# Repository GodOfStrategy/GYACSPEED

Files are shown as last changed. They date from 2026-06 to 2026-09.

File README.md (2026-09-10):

# GYACSPEED
Speedometer, accelerometer and a gyroscope for my bicycle, with the XIAO RP2040 as the MCU, with a 2.4" TFT (no touchscreen) display (connected with jumpers) for the information.
I saw the Hermes starter project and though, "Why only stop at a gyroscope?" and then answered my own question by adding a speedometer powered by the Ublox NEO-M9N GNSS module, and a gyroscope and an accelerometer powered by the LSM6DSLTR!! So that I can see my speed, acceleration, and how I take turn using the gyroscope and such, with the XIAO RP2040 serving as my MCU. I made this project because, well, I thought that Hermes was cool but then realized that only a gyroscope isn't that useful after all. I thought about an all-in-one bicycle dashboard, complete with a speedometer, odometer (calculated from the GPS module), accelerometer (to see the derivative of velocity ;) ). My bicycle isn't really a smart bicycle so it doesn't have all these features built-in like some other smart bicycles.
So, I drew the Schematics:

Then I routed the PCB

How my assembled PCB is supposed to look like:{270DA254-DB51-4898-A8E7-48D921C7D5DD}

Then I designed a case in Fusion 360 for my project, and found solutions so as to how will I mount it on my bicycle and then came up with this monstrosity:




The idea of the mount is to be modular and help me join the two parts by using a single mount. The mount is based on the idea of mounting the project on my bicycle handle bar. I took some measurements and made a cylinder with walls which would wrap around my bicycle bar. After that I added an extension to the cylinder with a flat base, where I added the screw holes. I then added a triangular kind of part to join the cylinder with my main project case.

Instructions on Assembling:
1. Solder the Header Pins.
2. seat the pcb into the top case.
3. Now there is an opening in the bottom of the top case to allow jumpers from the Li-Po to connect with the Main PCB as shown here: 
4. The hole on the side of the bottom [battery] case looks like so: 
5. Run two jumpers connecting the Battery to the PCB, the left pin on the main PCB is the +ve terminal, as mentioned on the silkscreen.
6. There are mounting holes on tft module that I will be purchasing, and I have also added holes on my case top so that I can secure the display. To do so, we place the Display on the bottom of the top case like so:  and then insert bolts(M3/ 15mm) form the top : and screw them with the nuts tightly.
7. Then we again use jumper wires to connect the display to the pcb 
after which we place the top case cover on the top case and put 30 mm M3 bolts through the screw holes and secure them with M3 nuts.
8. For the bottom case, we insert our battery in the main bottom case, run the jumpers to the main PCB through the openings, and then We put the case cover on, and screw it using M3 30mm bolts and M3 nuts.
9. Now, we have two modules, to mount them together on a bicycle handlebar, we simply put them on the bicycle bar and then screw the both together in this mount-ish-part 
using the screw holes, and M3 15mm bolts along with M3 nuts.
Thats it! You're done

Here is my BoM (which you can find in the root of my repository as well):

|Designator|Footprint|Quantity|Value|LCSC Part #|Price (US $)|Links|Distributor|Generic Name|
|---|---|---|---|---|---|---|---|---|
| C1 | 805 | 5.0 | 100uF |  | 3.54 | GRM21BR60E107ME15K Murata Electronics \| Mouser India | Mouser India | Capacitors |
| C10, C3, C4, C5 | 402 | 10.0 | 10uF |  | 0.46 | https://www.mouser.in/ProductDetail/TAIYO-YUDEN/MSASJ105CB5106MFNC12?qs=PBDs2xEllI8xKzMj03Wyvw%3D%3D | Mouser India |  |
| C11, C12, C7, C8, C9 | 402 | 5.0 | 0.1uF |  | 0.24 | https://www.mouser.in/ProductDetail/80-C0402C104K4P | Mouser India |  |
| C2 | 402 | 1.0 | 1pF |  | 0.25 | 04023A1R0DAT2A KYOCERA AVX \| Mouser India |  |  |
| C6 | 402 | 10.0 | 1uF |  | 0.17 | https://www.mouser.in/ProductDetail/KYOCERA-AVX/0402X5R105KTAAT?qs=XAiT9M5g4x9uZyL2wCxs9w%3D%3D | Mouser India |  |
| D1 | D_SMA | 3.0 | SS14 |  | 1.3 | https://www.mouser.in/ProductDetail/onsemi/SS14?qs=mVVXn4M53U%252BvrBaFv5vr4w%3D%3D | Mouser India | Reverse Polarity Protection diode |
| DS1 | TFT LCD 240x320 2.4" | 2.0 | TFT LCD 2.4" SPI |  | 16.53 | [https://www.amazon.in/Tishvi-Interface-Contrast-Microcontroller-Projects/dp/B0GZQBH8TX/ref=sr_1_5?](https://www.amazon.in/SmartElex-2-4-inch-Interface-Resolution-Embedded/dp/B0GFD2GKS3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)crid=5ELFGR2Y3AVB&dib=eyJ2IjoiMSJ9.Jpr0nalYGfL14nV7bbjmTZKJv2EIKupA4PS6ncRHPeflKUuEP1chaxLUuG31tnS91O83QhHNpJtINdHxloWLYH9lf4NJ4qSOWR6nymU5ejpQAXrm3idjtpBYQ0aIwBILTmNX_3lALKvsE76wo-qvywPqliJmu2u1Sw0mh8OCet7xKizlRF5dPz3CHCYLgBtFUnNA9Eu-mYQBGu7QWCQPqbfzEN95b4kUAEvBXaaM7DjF16ZafKrP9sBf0yOEFYHzo9n5p0J-zkTF9JNQ7vyMX4nY2xR5RTSpoe2_mFh8lyM.-pu-_CBvqfhh_vnW6SlNHAERV8AtyvnIy9OJlCs-LRc&dib_tag=se&keywords=1.3%22+OLED+IIC&qid=1782751854&sprefix=1.3+oled+iic%2Caps%2C282&sr=8-5 | Amazon India | OLED |
| E1 | XCVR_ANT-GNCP-TH25AL12 | 2.0 | ANT-GNCP-TH25AL12 |  | 22.2 | https://www.mouser.in/ProductDetail/TE-Connectivity/ANT-GNCP-TH25AL12?qs=A6eO%252BMLsxmRfsTs3t3ApUw%3D%3D | Mouser India | Passive antenna |
| J1, J2 | PinHeader_1x05_P2.54mm_Vertical | 0.0 | Conn_01x05_Pin |  | 0.0 |  | Self-Sourced |  |
| J3 | PinHeader_1x02_P2.54mm_Vertical |  | Conn_01x02_Socket |  |  |  |  |  |
| L1 | 603 | 1.0 | 1 uH |  | 0.52 | https://www.mouser.in/ProductDetail/ABRACON/AIML-0603-1R0K-T?qs=1vO2EIVe%252BY7DV5QHOd2BCw%3D%3D | Mouser India | Inductor |
| Q1, Q2 | SOT-23-3_L3.0-W1.7-P0.95-LS2.9-BR | 4.0 | SI2301CDS-T1-GE3 | C10487 | 3.47 | SI2301CDS-T1-BE3 Vishay / Siliconix \| Mouser India | Mouser India | MOSFETs |
| R1 | 402 | 1.0 | 453K |  | 0.088 | RC0402FR-07453KL YAGEO \| Mouser India | Mouser India | Resistors |
| R2 | 402 | 1.0 | 100K |  | 0.37 | https://www.mouser.in/ProductDetail/YAGEO/AC0805JR-7W100KL?qs=r5DSvlrkXmI4dHdBm%2FLHKQ%3D%3D | Mouser India |  |
| R3 | 402 | 1.0 | 2.2K |  | 0.078 | RC0402JR-7D2K2L YAGEO \| Mouser India | Mouser India |  |
| R4 | 402 | 1.0 | 330 |  | 0.078 | CR0402-JW-331GLF Bourns \| Mouser India | Mouser India |  |
| U1 | XIAO-RP2040-DIP | 2.0 | XIAO-RP2040-DIP |  | 10.57 | https://www.mouser.in/ProductDetail/Seeed-Studio/102010428?qs=Znm5pLBrcAJ75FCbdxzDHQ%3D%3D | Mouser India | MCU |
| U2 | XCVR_NEO-M9N-00B | 2.0 | NEO-M9N-00B |  | 23.69 | https://www.mouser.in/ProductDetail/u-blox/NEO-M9N-00B?qs=DPoM0jnrROVeJ6BHpcwcjw%3D%3D | Mouser India | GNSS Module |
| U3 | LGA-14_3x2.5mm_P0.5mm_LayoutBorder3x4y | 2.0 | LSM6DS3 |  | 13.42 | https://www.mouser.in/ProductDetail/STMicroelectronics/LSM6DSV32XTR?qs=HoCaDK9Nz5d%252BGVBpjxkjlg%3D%3D | Mouser India | 3D Gyroscope + Accelerometer |
| U4 | VQFN-7_L2.0-W2.0-P0.55-TL_RWU | 2.0 | TPS61022RWUR | C915088 | 6.31 | TPS61022RWUR Texas Instruments \| Mouser India | Mouser India | Swirching Buck Regulator |
| U5 | WSON-6_L1.5-W1.5-P0.50-TL | 2.0 | BQ29703DSER | C2876295 | 1.12 | BQ29703DSER Texas Instruments \| Mouser India | Mouser India | Battery overdischarge protection |
|  |  | 1.0 | (cheaper and better than any hotplate on amazon[reviews for the hotplate were horrible]) |  | 37.02 | https://www.amazon.in/Soldering-600W-Adjustable-Temperature-Electronics/dp/B0DT693N47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 | Amazon India | Hot air gun [ 2 in 1] |
|  |  | 1.0 |  |  | 6.34 | https://www.amazon.in/SR-Syringe-Circuit-Assembly-Mechanic-Soldering/dp/B0H511T6TD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 | Amazon India | Soldering Paste |
|  |  | 1.0 |  |  | 4.75 | https://www.amazon.in/Desoldering-Microprocessor-Smartphones-Motherboards-Electronic/dp/B0C7N66JFQ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 | Amazon India | Flux Paste |
|  |  | 10.0 |  |  | 2.91 | https://www.amazon.in/Rpi-shop-Phillips-Countersunk-Quantity/dp/B08HNBTZ3D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 | Amazon India | M3 bolts 15mm |
|  |  | 30.0 |  |  | 3.7 | https://www.amazon.in/Invento-pcs-Head-Screws-Projects/dp/B073Z9LXB2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 | Amazon India | M3 bolts 30mm |
|  |  | 50.0 |  |  | 1.51 | https://www.amazon.in/TRO-M3-3mm-HEX-NUT-SS304-PACK/dp/B0DSWCH2XN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 | Amazon India | M3 nuts |
|  |  | 10.0 |  |  | 0.93 | https://www.amazon.in/Female-2-5mm-Cable-Connector-Silicone/dp/B0837W4DC8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 | Amazon India | 2 pin 2.5mm Cable Micro Male and Female Connector Plug For Lithium Ion Battery connector |
|  |  | 1.0 |  |  | 6.31 | https://www.amazon.in/ELBOTICS-Rechargeable-Lithium-ion-Electronics-Helicopter/dp/B0F4KQPNNH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 | Amazon India | 2 cell LiPo [2000 maH] |
|  |  | 1.0 |  |  | 1.66 | https://www.amazon.in/Step-Up-Overvoltage-Protection-Efficiency-Electronics/dp/B0FDRCPRM8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 | Amazon India | 2 cell LiPo Charger |
|  |  | 1.0 |  |  | 21.58 |Shipping|  | SHIPPING (Mouser +JLCPCB) |
|  |  | 5.0 |  |  | 5.0 |PCBs from JLCPCB|  | PCB |
|  |  | 1.0 |  |  | 7.16 |Stencil so that I can solder them myself|  | Stencil |
|  |  |  |  |  |  |  |  |  |
|  | TOTAL --> |  | 203.89 $|  |  |  |  |  |

[bom(final).csv](https://github.com/user-attachments/files/29474485/bom.final.csv)

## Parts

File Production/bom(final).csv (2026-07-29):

Designator | Footprint | Quantity | Value | LCSC Part # | Generic Name | Price (US $) | Links | Comments | Distributor
C1 | 805 | 5 | 100uF |  | Capacitors | 2.51 | https://www.mouser.in/ProductDetail/Murata/GRM21BR60G107ME11L?qs=Ey7%2FXF42M3epBQcj%2F9hW%252BQ%3D%3D |  | Mouser India
C2, C4, C5 | 402 | 10 | 10uF |  |  | 0.46 | https://www.mouser.in/ProductDetail/TAIYO-YUDEN/MSASJ105CB5106MFNC12?qs=PBDs2xEllI8xKzMj03Wyvw%3D%3D |  | Mouser India
C3 | 402 | 5 | 22uF |  |  | 3.01 | https://www.mouser.in/ProductDetail/KYOCERA-AVX/04024W226MAT2A?qs=iLbezkQI%252BsiTzMwT1ZoG%252Bw%3D%3D |  | Mouser India
C6 | 402 | 5 | 1uF |  |  | 2.07 | https://www.mouser.in/ProductDetail/KYOCERA-AVX/0402X5R105KTAAT?qs=XAiT9M5g4x9uZyL2wCxs9w%3D%3D |  | Mouser India
C7, C8 | 402 | 5 | 0.1uF |  |  | 1.87 | https://www.mouser.in/ProductDetail/KYOCERA-AVX/0402X7R104KT2AT?qs=XAiT9M5g4x9OdY6eF8NA2w%3D%3D |  | Mouser India
D1 | D_SMA | 3 | SS14 |  | Reverse Polarity Protection Diode | 1.3 | https://www.mouser.in/ProductDetail/onsemi/SS14?qs=mVVXn4M53U%252BvrBaFv5vr4w%3D%3D |  | Mouser India
 |  | 2 |  |  | 2.4" SPI TFT LCD | 16.53 | https://www.amazon.in/SmartElex-2-4-inch-Interface-Resolution-Embedded/dp/B0GFD2GKS3 |  | Amazon India
E1 | XCVR_ANT-GNCP-TH25AL12 | 2 | ANT-GNCP-TH25AL12 |  | Ceramic Patch Antenna | 22.2 | https://www.mouser.in/ProductDetail/TE-Connectivity/ANT-GNCP-TH25AL12?qs=A6eO%252BMLsxmRfsTs3t3ApUw%3D%3D |  | Mouser India
J1, J2 | PinHeader_1x05_P2.54mm_Vertical | 2 | Conn_01x05_Pin |  | Pin headers | 0 |  |  | Self Sourced
J3 | PinHeader_1x02_P2.54mm_Vertical | 1 | Conn_01x02_Socket
L1 | 805 | 5 | 2.2uH |  | Inductor | 2.81 | https://www.mouser.in/ProductDetail/TDK/B82498F1222J?qs=iux7VCIsw53%252Bh%2F5GwBAxhg%3D%3D |  | Mouser India
PS1 | WSON-8_L2.0-W2.0-P0.50-TL-EP | 3 | TPS62163DSGR | C97534 | Switching Buck Regulator | 5.09 | https://www.mouser.in/ProductDetail/Texas-Instruments/TPS62163DSGR?qs=gXEV9p%2FxLgeWmbvztTvegw%3D%3D |  | Mouser India
R1 | 805 | 10 | 100K |  | Resistor | 0.37 | https://www.mouser.in/ProductDetail/YAGEO/AC0805JR-7W100KL?qs=r5DSvlrkXmI4dHdBm%2FLHKQ%3D%3D |  | Mouser India
R2 | 402 | 10 | 4.7K |  |  | 0.12 | https://www.mouser.in/ProductDetail/YAGEO/RC0402JR-104K7L?qs=qpJ%252B%252B%252Bdg6p1vPUiz5W4RZg%3D%3D |  | Mouser India
R3 | 402 |  |  |  |  |  |  |  | Mouser India
U1 | XIAO-RP2040-DIP | 2 | XIAO-RP2040-DIP |  | MCU | 10.57 | https://www.mouser.in/ProductDetail/Seeed-Studio/102010428?qs=Znm5pLBrcAJ75FCbdxzDHQ%3D%3D |  | Mouser India
U2 | XCVR_NEO-M9N-00B | 2 | NEO-M9N-00B |  | GNSS Module | 23.69 | https://www.mouser.in/ProductDetail/u-blox/NEO-M9N-00B?qs=DPoM0jnrROVeJ6BHpcwcjw%3D%3D |  | Mouser India
U3 | LGA-14_3x2.5mm_P0.5mm_LayoutBorder3x4y | 2 | LSM6DS3 |  | 3D Gyroscope + Accelerometer | 13.42 | https://www.mouser.in/ProductDetail/STMicroelectronics/LSM6DSV32XTR?qs=HoCaDK9Nz5d%252BGVBpjxkjlg%3D%3D |  | Mouser India
PCB |  |  |  |  |  | 4 |  |  | JLCPCB
Stencil |  |  |  |  |  | 7.16 |  |  | JLCPCB
 |  | 1 |  |  | Hot air gun [ 2 in 1] | 37.02 | https://www.amazon.in/Soldering-600W-Adjustable-Temperature-Electronics/dp/B0DT693N47 | (cheaper and better than any hotplate on amazon[reviews for the hotplate were horrible]) | Amazon India
 |  | 1 |  |  | Soldering Paste | 6.34 | https://www.amazon.in/SR-Syringe-Circuit-Assembly-Mechanic-Soldering/dp/B0H511T6TD |  | Amazon India
 |  | 1 |  |  | Flux Paste | 4.75 | https://www.amazon.in/Desoldering-Microprocessor-Smartphones-Motherboards-Electronic/dp/B0C7N66JFQ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 |  | Amazon India
 |  | 10 |  |  | M3 bolts 15mm | 2.91 | https://www.amazon.in/Rpi-shop-Phillips-Countersunk-Quantity/dp/B08HNBTZ3D |  | Amazon India
 |  | 30 |  |  | M3 bolts 30mm | 3.7 | https://www.amazon.in/Invento-pcs-Head-Screws-Projects/dp/B073Z9LXB2 |  | Amazon India
 |  | 50 |  |  | M3 nuts | 1.51 | https://www.amazon.in/TRO-M3-3mm-HEX-NUT-SS304-PACK/dp/B0DSWCH2XN |  | Amazon India
 |  | 10 |  |  | 2 pin 2.5mm Cable Micro Male and Female Connector Plug For Lithium Ion Battery connector | 0.93 | https://www.amazon.in/Female-2-5mm-Cable-Connector-Silicone/dp/B0837W4DC8?nsdOptOutParam=true |  | Amazon India
 |  | 1 |  |  | 2 cell LiPo [2000 maH] | 6.31 | https://www.amazon.in/ELBOTICS-Rechargeable-Lithium-ion-Electronics-Helicopter/dp/B0F4KQPNNH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 |  | Amazon India
 |  | 1 |  |  | 2 cell LiPo Charger | 1.66 | https://www.amazon.in/Step-Up-Overvoltage-Protection-Efficiency-Electronics/dp/B0FDRCPRM8 |  | Amazon India
SHIPPING (Mouser +JLCPCB) |  |  |  |  |  | 21.58 |  | Ordering hot air gun, solder paste etc. Because getting the tools and self assembling
 |  |  |  |  | TOTAL --> | 203.89 |  | is cheaper than JLCPCBA and helps future projects also be cheaper

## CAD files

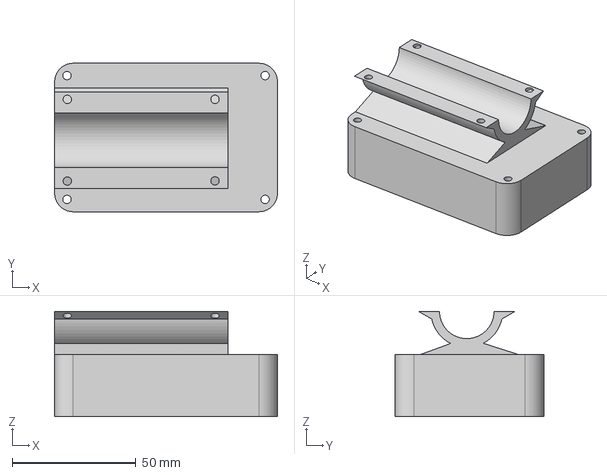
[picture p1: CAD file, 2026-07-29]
CAD/Bottom/Hermes Bottom [1].step
90.1 x 60.0 x 42.5 mm

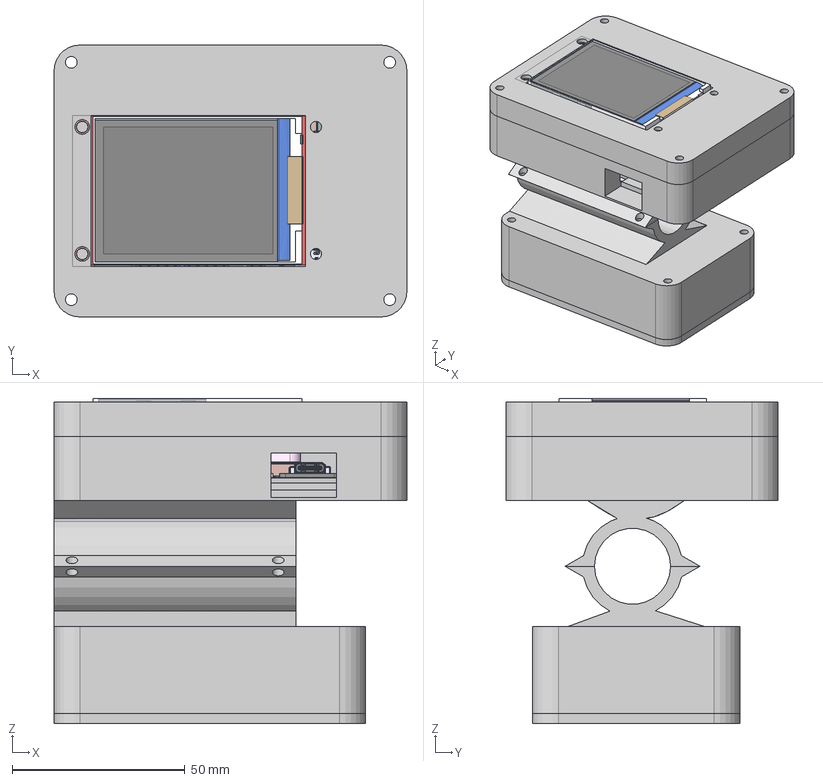
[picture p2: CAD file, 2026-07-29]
CAD/Full Assembled/Hermes [all].step
102.0 x 78.6 x 94.0 mm
SOT-23-3L_L2.9-W1.6-H1.1-LS2.8-P0.95 x 2
WSON-6_L1.5-W1.5-H0.8-P0.50-TL
R_0402_1005Metric x 4
VQFN-7_L2.0-W2.0-P0.55-TL_RWU
C_0402_1005Metric x 11
XIAO RP2040--3DModel-STEP-269445
ANT-GNCP-TH25AL12
C_0805_2012Metric
PinHeader_1x02_P2.54mm_Vertical
PinHeader_1x05_P2.54mm_Vertical x 2
PinHeader_1x04_P2.54mm_Vertical x 2
D_SMA
NEO-M9N_NEO-M9N
L_0603_1608Metric
LGA-14_3x2.5mm_P0.5mm_LayoutBorder3x4y
Hermes_silkscreen
Hermes_soldermask
Hermes_soldermask_1
Hermes_PCB
2.0 LCD TFT Module - Without Glass
0603 Resistor x 6
0603 Capacitor x 2
SOT23-3 x 2
2.4in TFT(Without Glass)- Tucked Cable

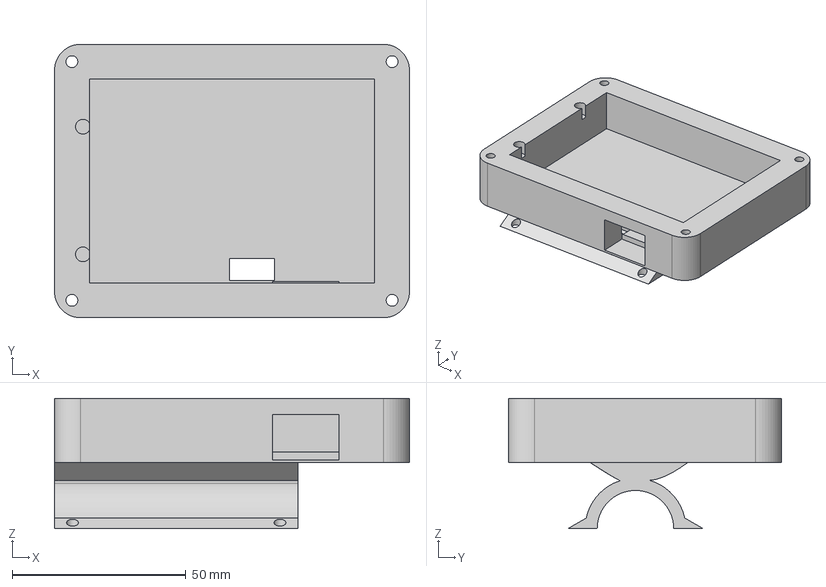
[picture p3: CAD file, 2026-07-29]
CAD/Top/Hermes top [1].step
102.0 x 78.6 x 37.5 mm

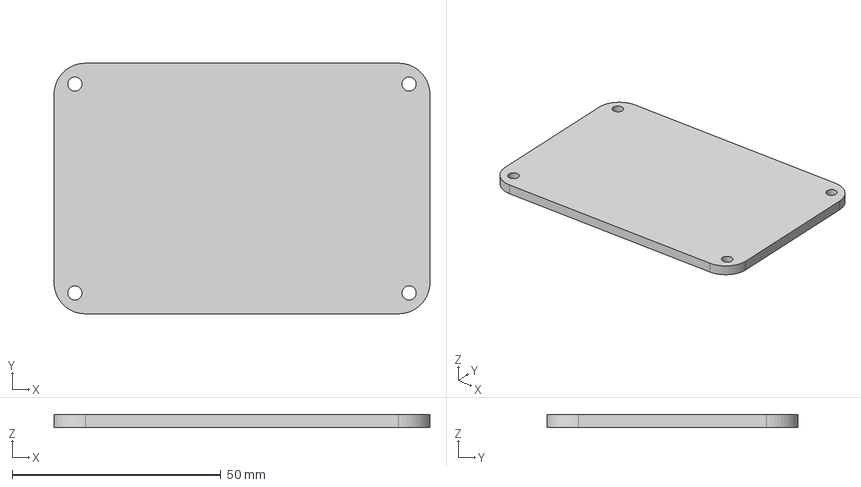
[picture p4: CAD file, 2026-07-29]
CAD/Bottom/Hermes Bottom [2].step
90.0 x 60.0 x 3.00 mm

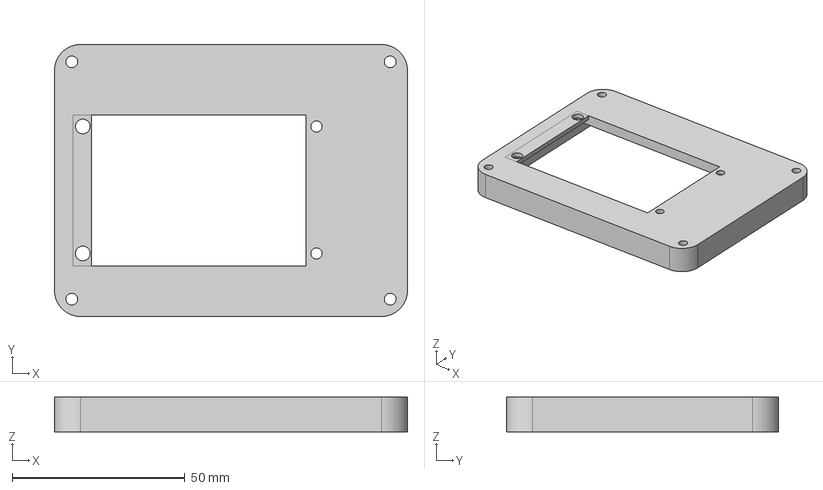
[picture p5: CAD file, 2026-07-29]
CAD/Top/Hermes top [2].step
102.0 x 78.6 x 10.0 mm

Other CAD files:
CAD/Hermesnew.f3z

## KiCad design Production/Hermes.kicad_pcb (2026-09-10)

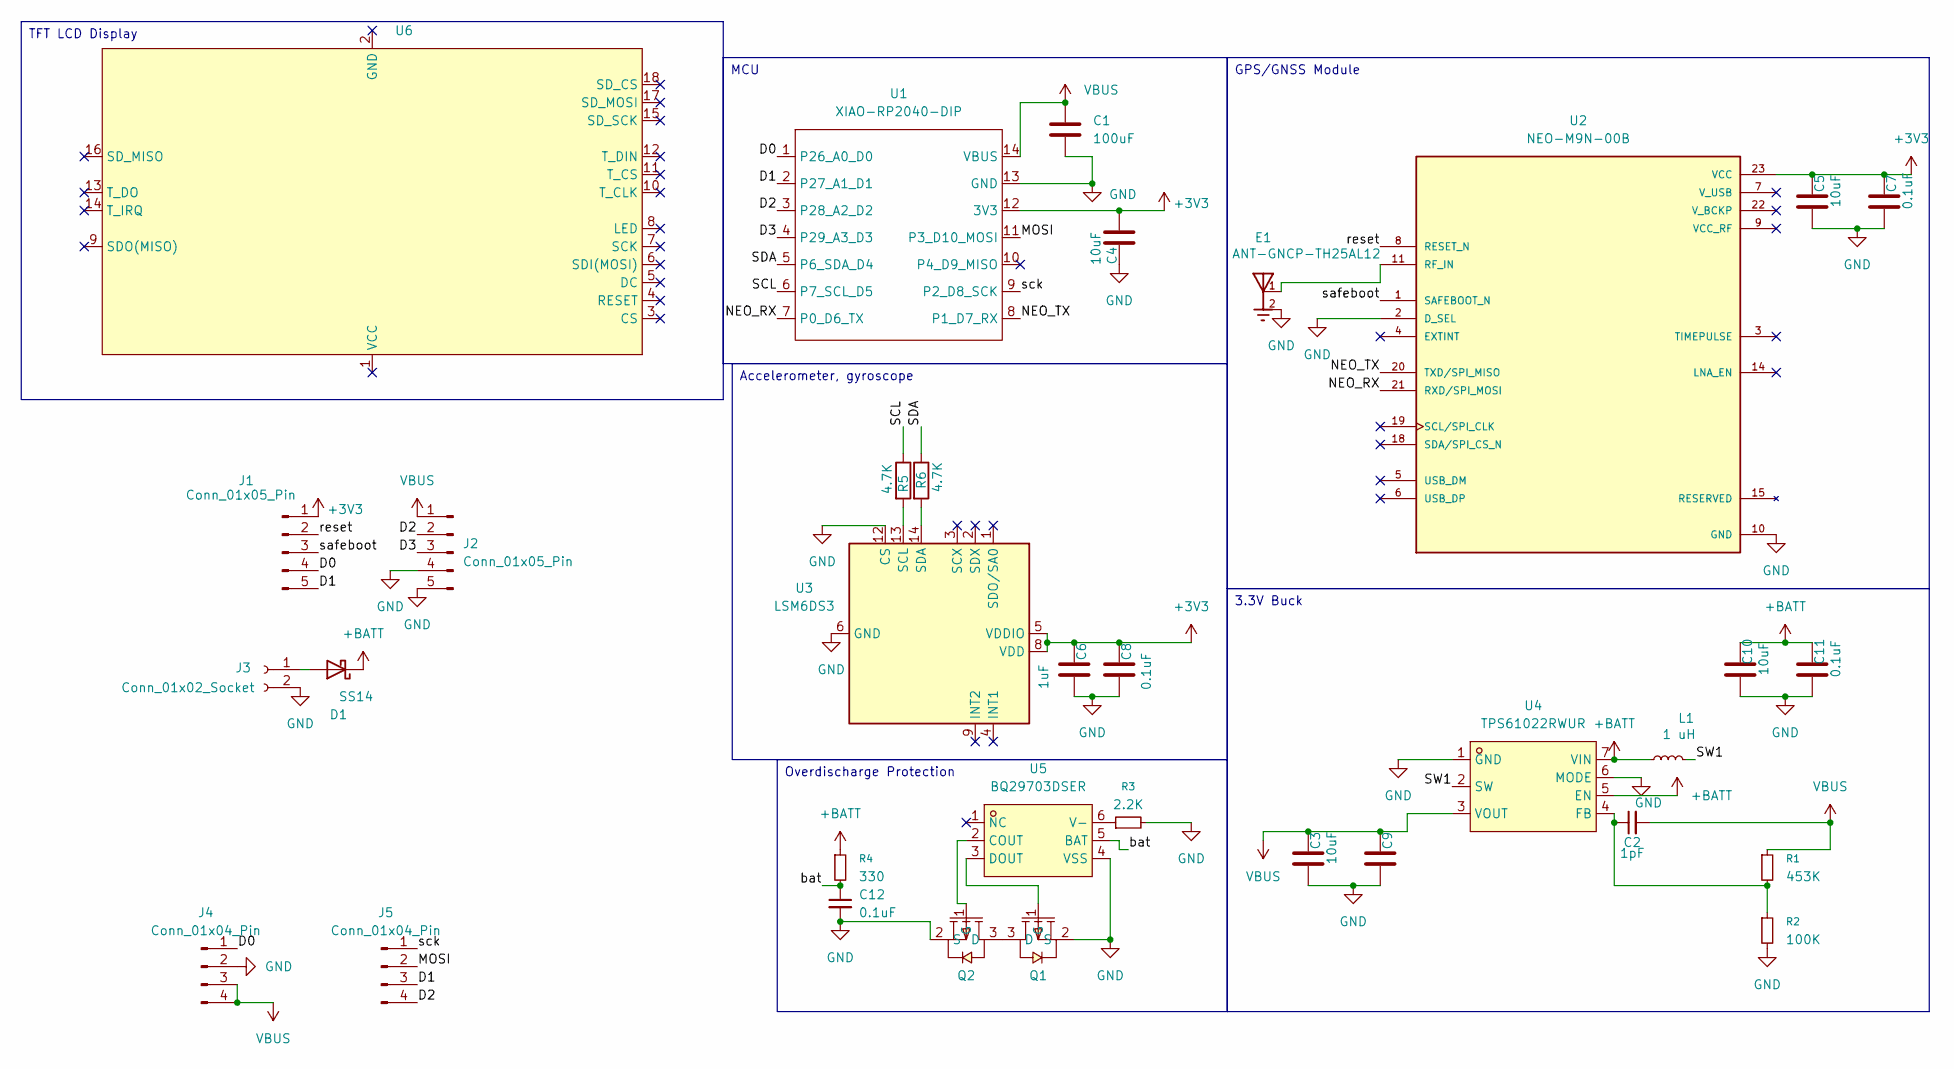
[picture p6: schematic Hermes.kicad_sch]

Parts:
C1: 100uF; C_0805_2012Metric
C2: 1pF; C_0402_1005Metric
C3, C4, C5, C10: 10uF; C_0402_1005Metric
C6: 1uF; C_0402_1005Metric
C7, C8, C9, C11, C12: 0.1uF; C_0402_1005Metric
D1: SS14; D_SMA
E1: ANT-GNCP-TH25AL12; XCVR_ANT-GNCP-TH25AL12; PARTREV A
J1, J2: Conn_01x05_Pin; PinHeader_1x05_P2.54mm_Vertical
J3: Conn_01x02_Socket; PinHeader_1x02_P2.54mm_Vertical
J4, J5: Conn_01x04_Pin; PinHeader_1x04_P2.54mm_Vertical
L1: 1 uH; L_0603_1608Metric
Q1, Q2: SI2301CDS-T1-GE3; SOT-23-3_L3.0-W1.7-P0.95-LS2.9-BR; MPN SI2301CDS-T1-GE3; LCSC Part C10487
R1: 453K; R_0402_1005Metric
R2: 100K; R_0402_1005Metric
R3: 2.2K; R_0402_1005Metric
R4: 330; R_0402_1005Metric
R5, R6: 4.7K; R_0402_1005Metric
U1: XIAO-RP2040-DIP
U2: NEO-M9N-00B; XCVR_NEO-M9N-00B; PARTREV R05
U3: LSM6DS3; LGA-14_3x2.5mm_P0.5mm_LayoutBorder3x4y
U4: TPS61022RWUR; VQFN-7_L2.0-W2.0-P0.55-TL_RWU; MPN TPS61022RWUR; LCSC Part C915088
U5: BQ29703DSER; WSON-6_L1.5-W1.5-P0.50-TL; MPN BQ29703DSER; LCSC Part C2876295
U6: 2.4'' 240x320 LCD Display TFT Module; 2.4_240x320_LCD_Display_TFT_Module

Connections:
+3V3: C4.2, C5.1, C6.1, C7.1, C8.1, J1.1, U1.12 (3V3), U2.23 (VCC), U3.5 (VDDIO), U3.8 (VDD)
+BATT: C10.1, C11.1, D1.1 (K), L1.1, R4.1, U4.5 (EN), U4.7 (VIN)
/D0: J1.4, J4.1, U1.1 (P26_A0_D0)
/D1: J1.5, J5.3, U1.2 (P27_A1_D1)
/D2: J2.2, J5.4, U1.3 (P28_A2_D2)
/D3: J2.3, U1.4 (P29_A3_D3)
/MOSI: J5.2, U1.11 (P3_D10_MOSI)
/NEO_RX: U1.7 (P0_D6_TX), U2.21 (RXD/SPI_MOSI)
/NEO_TX: U1.8 (P1_D7_RX), U2.20 (TXD/SPI_MISO)
/SCL: R5.1, U1.6 (P7_SCL_D5)
/SDA: R6.1, U1.5 (P6_SDA_D4)
/SW1: L1.2, U4.2 (SW)
/bat: C12.1, R4.2, U5.5 (BAT)
/reset: J1.2, U2.8 (RESET_N)
/safeboot: J1.3, U2.1 (SAFEBOOT_N)
/sck: J5.1, U1.9 (P2_D8_SCK)
GND: C1.2, C3.2, C4.1, C5.2, C6.2, C7.2, C8.2, C9.2, C10.2, C11.2, C12.2, E1.2, E1.3, E1.4, E1.5, J2.4, J2.5, J3.2, J4.2, Q1.2 (S), Q2.2 (S), R2.2, R3.2, U1.13 (GND), U2.2 (D_SEL), U2.10 (GND), U2.12 (GND), U2.13 (GND), U2.24 (GND), U3.6 (GND), U3.7 (GND), U3.12 (CS), U4.1 (GND), U4.6 (MODE), U5.4 (VSS)
unnamed: D1.2 (A), J3.1
unnamed: Q1.3 (D), Q2.3 (D)
unnamed: Q1.1 (G), U5.3 (DOUT)
unnamed: Q2.1 (G), U5.2 (COUT)
unnamed: E1.1, U2.11 (RF_IN)
unnamed: R5.2, U3.13 (SCL)
unnamed: R6.2, U3.14 (SDA)
unnamed: C2.1, R1.2, R2.1, U4.4 (FB)
unnamed: R3.1, U5.6 (V-)
VBUS: C1.1, C2.2, C3.1, C9.1, J2.1, J4.3, J4.4, R1.1, U1.14 (VBUS), U4.3 (VOUT)

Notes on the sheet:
GPS/GNSS Module
MCU
Accelerometer, gyroscope
TFT LCD Display
Overdischarge Protection
3.3V Buck

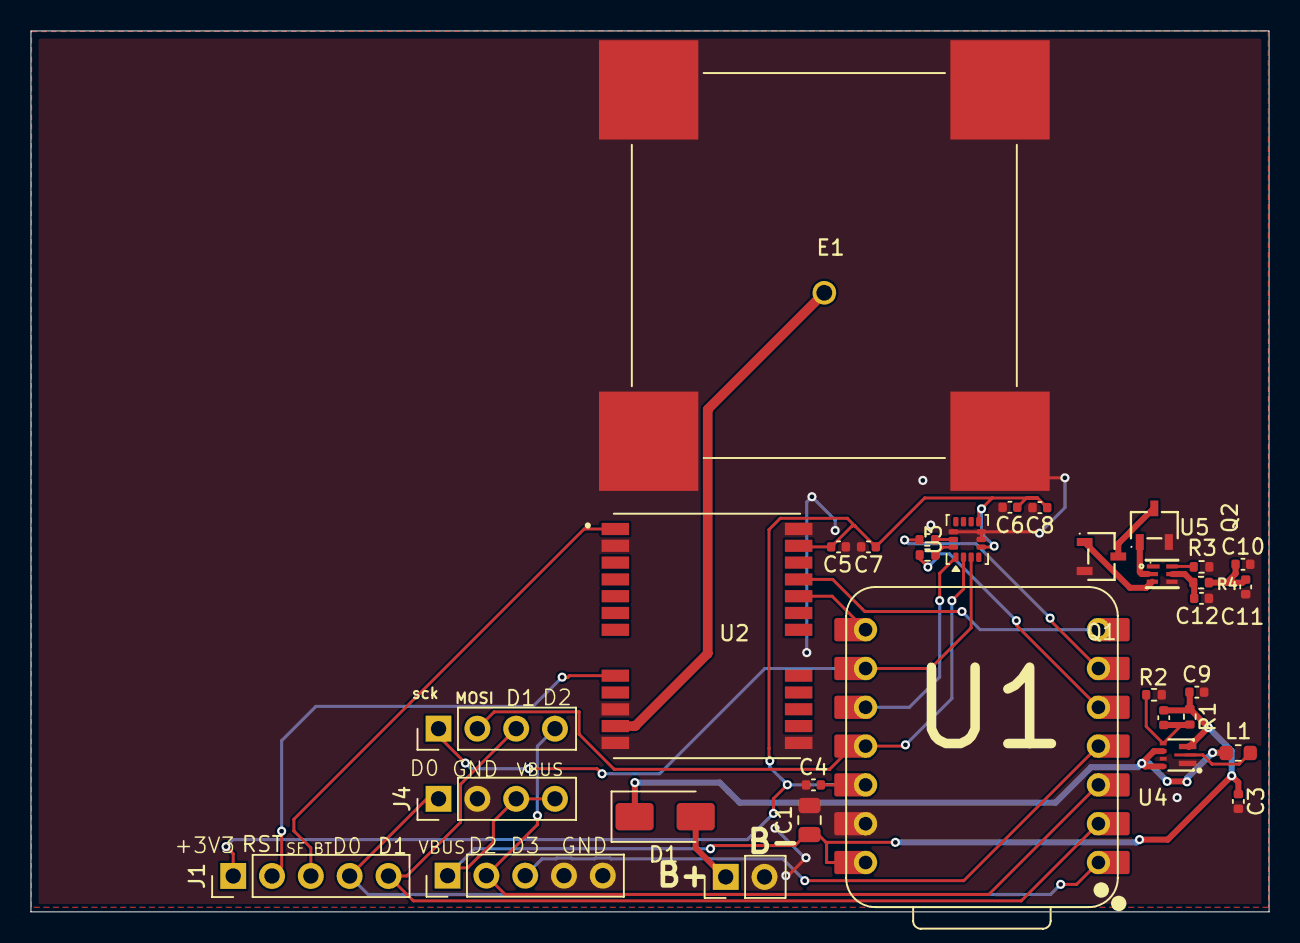
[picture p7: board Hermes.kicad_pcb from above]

Board: 2 copper layers, 81.0 x 57.7 mm, 33 parts (0 on the bottom side), 27 nets.

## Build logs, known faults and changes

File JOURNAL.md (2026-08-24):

# 8/24/2026 11:00AM – Impedance Matching
_Time spent: 0.25h_

I was given the feedback, to impedance match my trace, so I did it.
I removed the vias, because the distance they were adding between the rf trace and the ground plane were leading to some really big, and impractical values for the RF trace Width, like it was telling me to add 1.6 mm wide trace, to match the impedance. Therefore I removed the vias.




# 8/18/2026 11:00AM – Adding Assembly Instructions 
_Time spent: 0.33333h_  

I added assembly instructions to my README!








Lapse link: [https://lapse.hackclub.com/timelapse/eq9fp9hHtt8P](https://lapse.hackclub.com/timelapse/3rJiL33sXAL8)

# 7/29/2026 11:00AM – Case Remodel with TFT Display  
_Time spent: 1.88h_  

Last time I changed my PCB designs to include a TFT LCD display. Today I remodelled my case. I made a new Autodesk account to access Fusion 360 (since I can’t use the education license right now because my school is on holidays and won’t produce any documents).  

I imported the new 3D model for my PCB and display, removed the old models, and then tinkered with how to mount the display. I finally decided to screw it into the case top, which required extensive edits to make that possible. For the first time, I also filleted (rounded) the case corners — a small but exciting milestone in my CAD journey!  




Lapse link: https://lapse.hackclub.com/timelapse/eq9fp9hHtt8P

# 7/28/2026 9:25PM – CAD Platform Issues  
_Time spent: 0.483h_  

I was going to edit the case, but then Fusion said my free trial had expired. I tried to verify my educational institution, but it failed twice. So I moved on to Onshape, but there something strange kept occurring — glitched parts and mesh structures kept appearing unexpectedly!  



Lapse link: https://lapse.hackclub.com/timelapse/un3Wzf8xIZ_E
 
# 7/27/2026 - Display & Interface Update

_Time spent: 0.616h_

As per a suggestion by @Madhav, it would be better to use a TFT display instead of an OLED, because OLEDs don’t have enough brightness to be visible outdoors. Hence, I searched for a TFT display which is [SmartElex 2.4 inch TFT LCD](https://www.amazon.in/SmartElex-2-4-inch-Interface-Resolution-Embedded/dp/B0GFD2GKS3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).

Then, I went ahead and deleted the OLED symbol and schematics, and imported the symbol and footprint from [Choaib‑ELMADI’s KiCad library](https://github.com/Choaib-ELMADI/pcb-projects/blob/main/Libraries/2.4''%20240x320%20LCD%20Display%20TFT%20Module/footprints/2.4_240x320_LCD_Display_TFT_Module.pretty/2.4_240x320_LCD_Display_TFT_Module.kicad_mod).

I also have the dimensions from the Amazon vendor for the display, which I’ll be using as my dimensions for the case when I build it tomorrow.

Also, you may wonder why I didn’t continue with the Bluetooth chip. Well, that’s because there is simply no need to add a Bluetooth chip — I don’t know why I tried to add that initially, but eventually I realized it wasn’t really a great addition.

Finally, I changed the LSM6DS3 from SPI to I²C communication to allow my TFT to have the SPI connection.

Lapse link: https://lapse.hackclub.com/timelapse/uwCEZIGlqctU



# 7/26/2026 – CC2340R53 Exploration  
_Time spent: ~0.7h_  

Today I dove into the CC2340R53 and began understanding its power rails and debug/programming interfaces.  

- Learned that **VDDR** is the regulated RF domain supply rail, requiring bulk (10 µF) and local (100 nF) decoupling capacitors placed close to the pins.  
- Clarified how **C105** and other decoupling capacitors are connected: directly between VDDR and GND, with careful PCB placement.  
- Understood **DNM/DNP** markings in the schematic — optional footprints not populated by default, often used for tuning (like series resistors on crystals).  
- Confirmed that the CC2340R53 **cannot handle 5 V**; it operates strictly between 1.71–3.8 V, so a 3.3 V regulator is required when running from USB or other 5 V sources.  
- Reviewed **SWDIO/SWDCK** pins: ARM SWD debug interface, normally connected to a probe (XDS110, J‑Link, or RP2040 Picoprobe).  
- Considered using the **XIAO RP2040** as a programmer, but realized its SWD pads are underside golden circles — inaccessible once soldered.  
- Explored alternatives: adding a dedicated SWD header for CC2340R53 or using its **UART bootloader**.  
- Identified **Pin 6 = RX** and **Pin 7 = TX** on CC2340R53 for UART programming, cross‑connected to TX/RX of a USB‑UART adapter or the XIAO.  
- Researched reliable **USB‑to‑UART adapters**: FTDI FT232RL (best), CP2102 (good balance), CH340G (budget).  

Also, I started drawing schematics for the chip, added 2 crystals as shown in the datasheet, added decoupling capacitors, and also searched on how to upload data to the CC2340R53.  
Here's the lapse link :"https://lapse.hackclub.com/timelapse/8KGO7cviNVYR"



# 7/25/2026 6:30PM – Project Expansion  
_Time spent: 0.51666667h_  
My project was sadly moved to **Tier 3** by a reviewer last time, so I decided to make it more complex by adding **Bluetooth connectivity** and an **SD card**. The idea is to store the data from the gyroscope, accelerometer, etc., and then, when I bring it home to charge, transfer the data to my device and use firmware to make something meaningful out of it.  

With this in mind, I searched for a suitable chip and decided to use the **CC2340R53 BLE chip by Texas Instruments**.  


Lapse link: https://lapse.hackclub.com/timelapse/TdRiI4ZiH4CB

# 7/3/2026 4:10PM - BOM Progress
_Time spent:  1.4h_
Today I made a good BoM, carefully organizing the components and ensuring that everything aligns with the design requirements. This step felt like a solid milestone, since a well-prepared BoM makes the upcoming edits and procurement much smoother. It also gave me a clearer picture of how the project is shaping up and what refinements I’ll need to focus on next.
Here is the image of my bom:{42BB9702-31BB-45E9-9633-5F261E54E03D}
Lapse link:https://lapse.hackclub.com/timelapse/dtzv5QGsNK3_

# 7/1/2026 4:10 PM - Routing Update
_Time spent: 0.16666667h_
Today, I routed the BQ2970 and the TPS61022 and their passive components. Next time I will edit the BoM.

Here is the lapse: https://lapse.hackclub.com/timelapse/zb-mngRtFGg5

Here is the updated image of my PCB:  


---

# 7/1/2026 4 PM - A setback

_Time spent: 0.7833333333333333h_

After @John Meshstatic gave his valuable opinions on my project, he pointed out, that I didnt actually need a 7.4V LiPo, since everything runs on 3.3V, Including the OLED, which I though ran on 5V!. This basically rendered, the TPS62163DSRGR useless, along with john pointing out that my oled has the pull ups built in, I dont need to add them. I removed the pull ups, and I used TI's WEBENCH tool to find a suitable replacement, and that is where I found the TPS61022RWUR

So, I quickly did the schematics for that, and previously, I forgot that I had to include overdischarge protection, so for that I used the BQ29703DSER. Here is my updated schematic

here is the lapse: https://lapse.hackclub.com/timelapse/lyCJ2JbmvO7H




# 6/30/2026 8 AM - A Failed Attempt

_Time spent: 0.6h_

I just realised that the neo m9n and the antenna for it attracts customs, so I tried finding local suppliers, and in the prccess check arrow electronics, element14,robucraze etc. But none had what I needed, I also considered changing my gnss module to the quectel L76-M33, but it required more components like an LNA, which would make things expensive, so I dropped the plan. Lapse-https://lapse.hackclub.com/timelapse/1BQxWZEk1a9E
{269F88C1-10F7-4C57-B187-64F349850839}



# 6/29/2026 5 PM - Revising Stuff

_Time spent: 0.75h_

Today, I was told by @Tomas is #forge-help that I connected the decoupling capacitors wrong, and that I did not have pull up resistors on the SDA,SCL lines.


 So, I added the pull ups and also corrected the decoupling caapcitors and routed the new resistors and changed the routing of my decoupling capacitors to be as they should. Then, I regenerated the BoM using the JLCPCB fabrication toolkit plugin from KiCAD, soon enough to realised that I had just overwritten the BoM I made in my last session. I realised that I still had my old BoM on github, and I downloaded it, where only to add more things on my chest, I found that all the links I attached arent supported in the .csv format I guess? They just turned to normal text. Therefore I had to add all the links again manually

. Thats it for today! Here's the lapse link- https://lapse.hackclub.com/timelapse/iiIvF0IikTVY




# 6/27/2026 6 AM - Making a good BoM

_Time spent: 1.283333333333333h_

I made a good Bom, also tried to cost optimise it in various ways. 
Proof of choosing the cheapest Mouser shipping option:

Proof of cheapest JLCPCB Shipping option:





# 6/26/2026 9 AM - Moreeee CADD

_Time spent: 2.333333333333333h_

I figured out how to mount the battery, and I have no choice but to hang it from the bar just below the main device, because my bicycle does not have any other viable space. And also, I need a different length screw to join the two parts (the battery one is below and the main device is above) so I chose 15mm M3 for it, sicne it was the only one that fit. I also dont have a lapse today because apparently "SERVER A" was down and my session was lost in it.
{990F74D2-B75A-4538-9431-2918054D944E}

#hq-engineering at 14:25 (IST) on 26/06/2026 (DD/MM/YY).
 
{BEC9241A-0C7D-47AE-A8E4-D1B4F4F8977E}










# 6/25/2026 9 AM - More CAD

_Time spent: 2.1h_

I made the case top, changed screw size from M2.5 to M3, since it was hard finding long M2.5 screws for cheap, but I founr cheap M3 scerws, so I changed my hole size to 3.4mm diameter accounting for the tolerances. I also took measurements of my bicycle bar and the middle bar (where I aim to mount the battery) and made the mount. For my bar mount, I first made 2 semicircles with 3mm difference in their radii, and then I used the line tool to draw a line 5mm from the edge of the larger semi-circle and used the line tool to draw another line from the previous line end with an angle of 150 degrees, and I choose to end the line wherever the 150 degree line met the larger circle. I then extruded it with my desired bar length (70mm) and added the M3 holes in it.







# 6/17/2026 3 PM - CAD

_Time spent: 1.1h_

I started designing a Cad for this (I'll do the mounting later). So, taking some concepts from the blueprint hackpad guide, I started to design a case in the same manner, and made the base, and body, with the screw holes. I also added the base and body for the Battery pack (which I think, I need to mount on a different under  side [since it's easier to just hang heavy things] of my bicycle's handle bar to keep everything balanced). Here is a [Lapse](https://lapse.hackclub.com/timelapse/38pi_Iydz0pG) showing my work today.
{09145725-2526-4C75-BFA5-349398DCDCAE}



# 5/27/2026 5 PM - Part selection, comparision etc

_Time spent: 4.933333333333334h_

After I uploaded my gerber files to JLCPCB, and selected the PCBA option, I was prompted to select standard PCBA, since the NEO-M9N-00B & LSM6DS3 are not compatible in economic PCBA, so, I thought of checking if orddering all the parts and ordering everything I need to do the SMD soldering myself, be cheaper or not. So I spent a few hours filling my Mouser cart with all the smd components except the LSM6DS3 which I need to source from Amazon for crazy expensive (9.23$ for an IC !), but even after all this, the most cost effective option would be self assembling the PCB by ordering all the parts I need to SMD solder, and not get PCBA by about 3$.
This is the rough estimate of self assembling:



This is the rough total of JLCPCB PCBA (ohh and not to mention the customs that would apply aswell, I personally prefer the self assembling one, sinci I dont have to care about customs):






# 5/25/2026 3 PM - Completed PCB routing

_Time spent: 4.55h_

I routed the PCB the first time, but then everything did not fit in 100 x100 mm, then I tried the second and third time, I only got till 102mm. So I deleted everything and started over, this time I kept compactness in mind and did get it under 100x100mm. Then I resolved all DRC errors, and added all 3D models for all


This is my completed PCB:



This is my 3D render:







# 5/19/2026 7 AM - Starting Schematics

_Time spent: 4.333333333333333h_

So, I started making the scheamtics and reached here

, and I realised that my OLED woudnt work with 3.3 V that the xiao would output form it's 3.3V, and by LiPo was also 3.7V (nom) which isnt enough, so I switched to a new LiPo, a 7.4V with 2000maH capacity! [New LiPo :) ](https://www.amazon.in/ELBOTICS-Rechargeable-Lithium-ion-Electronics-Helicopter/dp/B0F4KQPNNH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)

But, now another issue is, that the XIAO only supports 5V max at its VBUS, so I need to add a buck converter (efficient) to turn the 7.4 V to 5V, which I can supply to the OLED and the XIAO. And I went to [Buck convertor calculator (by TI) ](https://webench.ti.com/power-designer/switching-regulator?base_pn=TPS62160&origin=ODS&litsection=application)
and put in my requirements there like so:


and clicked view options.
From there, I Chose the one with the perfect balance of efficiency and cost effectiveness 

the TPS62160 with 90% efficiency. Then i opened the Datasheet of the TPS62160 found this reference circuit 

 and implemented it!

(I later realised I chose the wrong model, frist I used the TPS62160, but after checking the datasheet, for the 5V/1A option, I was uspposed to use 62163, so I imported the footprint and symbol again and redid all connections related to that) 
I also need to change my Battery charging module, since I have a 2 cell LiPo, the TP4056 cannot charge it, so I selected this cheap battery charging module that supports 2 cell charging at 7.4V [New charger Module! ](https://www.amazon.in/Step-Up-Overvoltage-Protection-Efficiency-Electronics/dp/B0FDRCPRM8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)
Here are my finished scheamtics:









# 5/18/2026 1 PM - Sensor selection and thorough planning

_Time spent: 4h_

I decided to make this for my bicycle, as a speedometer, accelerometer and a gyroscope. For the gyroscope and accelerometer, I found a good candidate, the LSM6DS3TR-C IMU, which does both. I then chose a GNSS module for my speedometer, which  is the NEO-M9N-00B with a ceramic patch antenna (ANT‑GNCP‑TH25AL12) with it. I will display all this information on my OLED. 

Communication protocols:
I2C- for the display
UART- for the NEO-M9N-00B
SPI (4-wire) - for the LSM6DS3TR-C 
The XIAO RP-2040 has all these communication protocols.
(Note- I checked the datasheets of all these components to make sure they support their respective communication protocols.)
(One more thing- I also checked LCSC to make sure they have the stock for all these sensors :D )


Power:
 I plan to use a LiPo battery to power it while I am cycling and charge it when I am not cycling.
I want to use a 2000 mah LiPo which is linked here
[LiPo](https://www.amazon.in/KP-Original-Battery-Rechargeable-KP-603048/dp/B0GM6RKSB4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)
Which according to the calculations:
RP2040 MCU → ~30 mA

NEO‑M9N GPS → ~40–50 mA

SH1106 OLED (I²C) → ~10–20 mA

LSM6DS3TR‑C IMU (SPI) → 0.9 mA  
Total ≈ 82–100 mA average load

gives me about 15 hours of battery life accounting for all losses, which is great!

I also need to add a battery charging IC, because the XIAO 2040 doesnt include it. And for that, I will be using the TP 4056 module (I already have like 18 of these lying around).

I will be designing a case in Fusion 360 for this, which will have 2 parts- 
1) The display and electronics
2) The mounting
I am thinking of using a hollow cylinder kind of set up with mouting screws which will cover my bicycle's handle bar, and can be removed by unscrewing the screws. This will stay fixed always. The display and eletronics will be mounted on the mount using velcro, allowing me to take my module home and charge it without having to carry a screw driver with me always.

That's it, I hope this turns out great.



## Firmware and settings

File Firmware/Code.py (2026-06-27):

import time
import board
import busio
import displayio
import terminalio
from adafruit_display_text import label
import adafruit_sh1106
import adafruit_lsm6ds.lsm6dsl as LSM6DSL
import adafruit_gps

# --- I2C OLED setup ---
i2c = busio.I2C(board.SCL, board.SDA)
display_bus = displayio.I2CDisplay(i2c, device_address=0x3C)
oled = adafruit_sh1106.SH1106(display_bus, width=128, height=64)

# --- SPI IMU setup ---
spi = busio.SPI(board.SCK, board.MOSI, board.MISO)
imu_cs = board.D2   # Chip Select pin for IMU
lsm6dsl = LSM6DSL.LSM6DSL(spi, imu_cs)

# --- UART GPS setup ---
uart = busio.UART(board.TX, board.RX, baudrate=9600, timeout=1)
gps = adafruit_gps.GPS(uart, debug=False)
gps.send_command(b'PMTK220,1000')   # Update rate: 1 Hz
gps.send_command(b'PMTK314,0,1,0,0,0,0,0,0,0,0,0,0,0,0,0,0,0,0,0')  # GPRMC only

# --- Display group ---
splash = displayio.Group()
oled.show(splash)

text_area = label.Label(terminalio.FONT, text="Init...", color=0xFFFFFF, x=0, y=10)
splash.append(text_area)

while True:
    # --- Read IMU ---
    accel_x, accel_y, accel_z = lsm6dsl.acceleration
    gyro_x, gyro_y, gyro_z = lsm6dsl.gyro

    # --- Read GPS ---
    gps.update()
    speed_kmh = None
    if gps.has_fix and gps.speed_knots is not None:
        speed_kmh = gps.speed_knots * 1.852  # knots → km/h

    # --- Update OLED ---
    text_lines = [
        f"Accel: {accel_x:.2f}, {accel_y:.2f}, {accel_z:.2f} m/s^2",
        f"Gyro: {gyro_x:.2f}, {gyro_y:.2f}, {gyro_z:.2f} dps",
        f"Speed: {speed_kmh:.2f} km/h" if speed_kmh else "Speed: ---"
    ]
    splash.pop()
    text_area = label.Label(terminalio.FONT, text="\n".join(text_lines), color=0xFFFFFF, x=0, y=10)
    splash.append(text_area)

    time.sleep(1)
